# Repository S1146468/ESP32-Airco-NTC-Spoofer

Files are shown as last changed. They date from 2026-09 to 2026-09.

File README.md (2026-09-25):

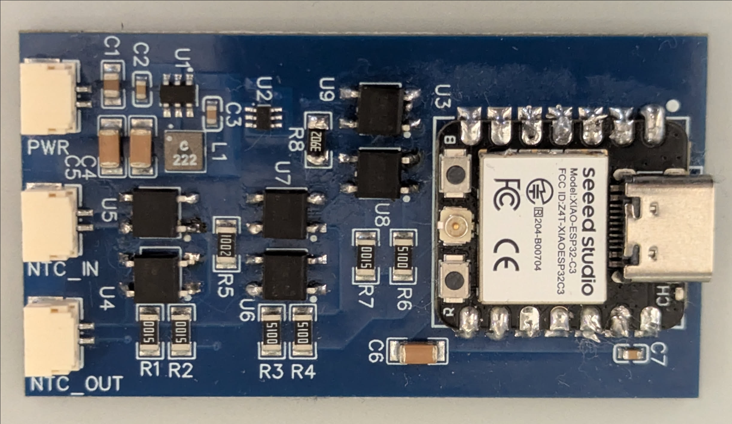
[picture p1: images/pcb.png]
PCB


# ESP32 Airco NTC Spoofer

An ESP32-C3 based open-hardware controller for improving the temperature regulation of a portable air conditioner by taking control of its NTC temperature-sensor input.

Instead of switching mains power or directly controlling the compressor, this project leaves the air conditioner's own electronics in charge and changes only the temperature resistance presented to its NTC input.

## Project goal

The goal of this project is to make a portable air conditioner regulate the temperature of the **room**, rather than relying only on the temperature measured by the air conditioner's built-in NTC sensor.

In my installation, the stock NTC measurement did not represent the room temperature very well. The temperature could continue drifting significantly after the air conditioner had started cooling, resulting in poor regulation and noticeable overshoot.

### Stock NTC

The following trace shows the system operating with the original air-conditioner NTC control.

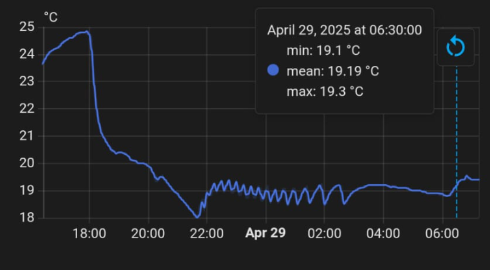
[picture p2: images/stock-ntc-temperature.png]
Temperature with stock NTC


The built-in control reacts to the temperature measured at the air conditioner itself. Depending on the unit, airflow, sensor placement, and room layout, that temperature can differ substantially from the temperature at the location that actually matters.

### With the NTC spoofer

The following trace shows the same air conditioner being controlled through the ESP32 NTC spoofer.

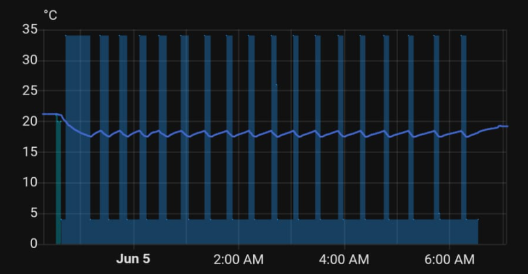
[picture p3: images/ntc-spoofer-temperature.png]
Temperature with ESP32 NTC spoofer


With the spoofer active, a Home Assistant room-temperature sensor becomes the input for an ESPHome thermostat.

The air conditioner is then deliberately shown one of two simulated NTC temperatures:

```text
35 °C -> cooling required
5 °C  -> target satisfied
```

The large transitions in the second graph are therefore intentional. They are the simulated NTC temperatures used to make the air conditioner's own controller start or stop requesting cooling.

The actual room-temperature trace can then be regulated using the external room sensor instead of depending on the location of the air conditioner's internal NTC.

These plots are examples from my installation rather than a controlled laboratory A/B test, but they illustrate the problem this project is intended to solve.

## How it works

The PCB sits between the air conditioner's original NTC sensor and the air-conditioner controller.

It can present one of three states:

```text
                         +----------------------+
Original NTC ------------|                      |
                         |  ESP32 NTC Spoofer   |----> Air-conditioner NTC input
39 kΩ / ~5 °C -----------|                      |
                         |                      |
10 kΩ / ~35 °C ----------|                      |
                         +----------------------+
                                   ^
                                   |
                              XIAO ESP32-C3
```

The ESP32 does **not** directly control the compressor.

The portable air conditioner's original controller still handles:

- compressor operation;
- internal compressor protection;
- fan behaviour;
- fault handling;
- the rest of the normal air-conditioner control logic.

The ESP32 only changes the temperature resistance seen at the NTC input.

## Control principle

The ESPHome firmware receives the room temperature and air-conditioner state from Home Assistant.

When cooling is required:

```text
Room too warm
    |
    v
ESPHome thermostat -> COOL
    |
    v
35 °C spoof selected
    |
    v
Air conditioner sees a warm NTC
    |
    v
Air conditioner continues cooling
```

When the target temperature has been reached:

```text
Target satisfied
    |
    v
ESPHome thermostat -> IDLE
    |
    v
5 °C spoof selected
    |
    v
Air conditioner sees a cold NTC
    |
    v
Air conditioner stops requesting cooling
```

When external control is inactive, the original NTC is reconnected.

## Hardware fail-safe

The PCB is designed so that loss of control power returns the NTC interface to the original sensor path:

```text
Original NTC -> connected
5 °C spoof   -> disconnected
35 °C spoof  -> disconnected
```

The original NTC path uses normally-closed PhotoMOS relays, while the spoof paths use normally-open PhotoMOS relays.

This means the hardware falls back to the air conditioner's own sensor when the controller is not powered.

## GPIO mapping

The corrected PCB and firmware mapping is:

| XIAO ESP32-C3 | GPIO | Function |
|---|---:|---|
| D2 | GPIO4 | Original air-conditioner NTC path |
| D3 | GPIO5 | 5 °C spoof path / 39 kΩ |
| D4 | GPIO6 | 35 °C spoof path / 10 kΩ |

The resistor values and firmware GPIO mapping must agree with the PCB.

## Firmware

Two ESPHome configurations are included.

### Two-room version

[`firmware/esp32-airco-ntc-spoofer-double-room.yaml`](firmware/esp32-airco-ntc-spoofer-double-room.yaml)

Supports two Home Assistant room-temperature sensors and an `Airco Area` selector:

```text
None
Room 1
Room 2
```

This version preserves the behaviour of the original two-room firmware.

### Single-room version

[`firmware/esp32-airco-ntc-spoofer-single-room.yaml`](firmware/esp32-airco-ntc-spoofer-single-room.yaml)

Uses one fixed Home Assistant room-temperature sensor and contains additional software fail-safe checks.

For the complete firmware explanation, configuration instructions, diagrams, thermostat behaviour, and compressor timing procedure, see:

**[Firmware documentation](firmware/firmware.md)**

## Hardware

The repository includes the complete PCB design and manufacturing files:

- EasyEDA schematic source;
- EasyEDA PCB source;
- schematic PDF;
- PCB PDF;
- Gerbers;
- BOM;
- pick-and-place file;
- OBJ mechanical model.

For PCB details, component information, manufacturing settings, and hardware verification, see:

**[Hardware documentation](hardware/hardware.md)**

## Repository structure

```text
ESP32-Airco-NTC-Spoofer/
├── README.md
├── LICENSE.md
├── LICENSES/
│   ├── CERN-OHL-S-2.0.txt
│   └── GPL-3.0-only.txt
│
├── images/
│   ├── stock-ntc-temperature.png
│   └── ntc-spoofer-temperature.png
│
├── firmware/
│   ├── firmware.md
│   ├── esp32-airco-ntc-spoofer-double-room.yaml
│   ├── esp32-airco-ntc-spoofer-single-room.yaml
│   ├── secrets.example.yaml
│   └── docs/
│
└── hardware/
    ├── hardware.md
    ├── assembly/
    ├── bom/
    ├── docs/
    ├── easyeda/
    ├── gerbers/
    └── mechanical/
```

## Getting started

A typical build consists of:

1. Manufacture and assemble the PCB using the files in [`hardware/`](hardware/).
2. Verify the original NTC fallback path before connecting the board to the air conditioner.
3. Connect the original NTC to `NTC_IN`.
4. Connect `NTC_OUT` to the air conditioner's NTC input.
5. Power the controller according to the schematic.
6. Choose the single-room or two-room ESPHome configuration.
7. Configure the Home Assistant entity IDs and ESPHome secrets.
8. Compile and flash the XIAO ESP32-C3.
9. Verify the 5 °C, 35 °C, and original-NTC states.
10. Observe several normal cooling cycles before relying on the system unattended.

See the [firmware documentation](firmware/firmware.md) and [hardware documentation](hardware/hardware.md) for the detailed procedure.

## Compressor cycling

Because this project adds an external thermostat in front of the air conditioner's own control system, the ESPHome thermostat includes minimum ON and OFF times.

The default configuration is:

```yaml
min_off_time: "4min"
min_on_time: "6min"
min_idle_time: "0s"
```

These values should be checked against the behaviour and documentation of the air conditioner being controlled.

The firmware documentation contains a practical procedure for measuring normal compressor cycling with a power-monitoring smart plug:

[Compressor timing and tuning](firmware/firmware.md#tuning-min_off_time-and-min_on_time)

## Important limitations

This project is intended for low-voltage NTC sensor interfacing.

It is **not** a mains-power switching project.

Before using the controller:

- verify the NTC connector pinout;
- verify the board-power connector pinout;
- verify the spoof resistances with a multimeter;
- verify that the original NTC is restored when control is inactive;
- verify normal compressor cycling;
- use manufacturer or service-manual protection limits when available.

The resistance-to-temperature relationship is specific to the NTC curve used by the air conditioner. The 39 kΩ and 10 kΩ values are the values used for this particular design and should not automatically be assumed to match every air conditioner.

## Project status

The project contains a working hardware design, manufacturing outputs, and ESPHome firmware for controlling a portable air conditioner through its NTC input.

The current hardware uses:

```text
XIAO ESP32-C3
CPC1117NTR normally-closed PhotoMOS relays
CPC1017NTR normally-open PhotoMOS relays
39 kΩ cold-spoof resistor
10 kΩ warm-spoof resistor
```

If adapting the project to another air conditioner, first determine the NTC resistance curve and verify that the spoof resistance values are appropriate for that unit.

## License

This repository contains separately licensed firmware and hardware.

| Part | License |
|---|---|
| Firmware / software | GNU GPL v3 only (`GPL-3.0-only`) |
| Hardware design | CERN Open Hardware Licence v2 - Strongly Reciprocal (`CERN-OHL-S-2.0`) |

See [LICENSE.md](LICENSE.md) for the licensing overview and [`LICENSES/`](LICENSES/) for the full license texts.

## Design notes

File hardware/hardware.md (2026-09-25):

# Hardware

This directory contains the editable PCB design, fabrication outputs, assembly data, mechanical export, and reference documentation for the **ESP32 Airco NTC Spoofer**.

The board is designed to sit between a portable air conditioner's original NTC temperature sensor and the air-conditioner controller. An ESP32-C3 can select the original NTC or one of two fixed-resistance spoof paths.

The PCB does **not** directly switch the compressor or mains power. It only changes what the air conditioner's NTC input sees.

For firmware setup and thermostat behaviour, see:

[../firmware/firmware.md](../firmware/firmware.md)

## Contents

### Editable EasyEDA source

- [Schematic source](easyeda/SCH_ESP32-Airco-NTC-Spoofer-Schematic.json)
- [PCB source](easyeda/PCB_ESP32-Airco-NTC-Spoofer-PCB.json)

### Design documents

- [Schematic PDF](docs/Schematic_ESP32-Airco-NTC-Spoofer.pdf)
- [PCB PDF](docs/PCB_ESP32-Airco-NTC-Spoofer-PCB.pdf)

### Manufacturing files

- [Gerber ZIP](gerbers/Gerber_ESP32-Airco-NTC-Spoofer.zip)
- [Individual Gerber and drill files](gerbers/Gerber_Export/)
- [Bill of materials](bom/BOM_ESP32-Airco-NTC-Spoofer.csv)
- [Pick-and-place file](assembly/PickAndPlace_ESP32-Airco-NTC-Spoofer-PCB.csv)

### Mechanical files

- [OBJ 3D model](mechanical/OBJ_ESP32-Airco-NTC-Spoofer-PCB.obj)
- [OBJ material file](mechanical/OBJ_ESP32-Airco-NTC-Spoofer-PCB.mtl)

## Directory structure

```text
hardware/
├── assembly/
│   └── PickAndPlace_ESP32-Airco-NTC-Spoofer-PCB.csv
├── bom/
│   └── BOM_ESP32-Airco-NTC-Spoofer.csv
├── docs/
│   ├── PCB_ESP32-Airco-NTC-Spoofer-PCB.pdf
│   └── Schematic_ESP32-Airco-NTC-Spoofer.pdf
├── easyeda/
│   ├── PCB_ESP32-Airco-NTC-Spoofer-PCB.json
│   └── SCH_ESP32-Airco-NTC-Spoofer-Schematic.json
├── gerbers/
│   ├── Gerber_ESP32-Airco-NTC-Spoofer.zip
│   └── Gerber_Export/
├── mechanical/
│   ├── OBJ_ESP32-Airco-NTC-Spoofer-PCB.mtl
│   └── OBJ_ESP32-Airco-NTC-Spoofer-PCB.obj
└── hardware.md
```

## Hardware overview

The design contains three selectable NTC paths:

1. the original air-conditioner NTC;
2. a fixed resistance representing approximately **5 °C**;
3. a fixed resistance representing approximately **35 °C**.

The ESP32 does not measure the air conditioner's NTC input. It controls solid-state relays that determine which path is presented to the air-conditioner controller.

Conceptually:

```text
 Original NTC
     |
     +-------------------+
                         |
 39 kΩ / 5 °C spoof ----+----> NTC switching ----> Air-conditioner NTC input
                         |
 10 kΩ / 35 °C spoof ---+
                         ^
                         |
                    XIAO ESP32-C3
```

The exact relationship between resistance and simulated temperature depends on the NTC curve used by the air conditioner. The 39 kΩ and 10 kΩ values are the values used in this design.

## NTC switching architecture

### Original NTC path

The original sensor path uses:

```text
U4, U5 -> CPC1117NTR
```

These devices form the original NTC pass-through path.

The hardware is designed so that the original NTC path is the fallback state when the control electronics are not actively spoofing the temperature.

### 5 °C spoof path

The 5 °C spoof path uses:

```text
R5 = 39 kΩ
GPIO5 / XIAO D3
NTC_5C
```

The firmware activates this path when it wants the air conditioner to see a cold temperature.

### 35 °C spoof path

The 35 °C spoof path uses:

```text
R8 = 10 kΩ
GPIO6 / XIAO D4
NTC_35C
```

The firmware activates this path when it wants the air conditioner to see a warm temperature.

### GPIO mapping

The PCB and firmware must use the same mapping:

| XIAO ESP32-C3 | GPIO | PCB net | Function |
|---|---:|---|---|
| D2 | GPIO4 | `NTC_AIRCO` | Original NTC path control |
| D3 | GPIO5 | `NTC_5C` | 5 °C spoof path |
| D4 | GPIO6 | `NTC_35C` | 35 °C spoof path |

For the matching firmware configuration, see:

[../firmware/firmware.md](../firmware/firmware.md)

## Fail-safe behaviour

The hardware uses different relay types for the original sensor path and the spoof paths.

The intended unpowered / fallback state is:

```text
Original NTC -> connected
5 °C spoof   -> disconnected
35 °C spoof  -> disconnected
```

This is important because a loss of ESP32 control should return temperature sensing to the original air-conditioner NTC rather than intentionally forcing either spoof resistance.

The firmware should preserve the same principle whenever external control is inactive.

Before installing the board, verify this behaviour with a multimeter.

## Main components

The current BOM contains the following major devices:

| Reference | Part | Function |
|---|---|---|
| U3 | XIAO ESP32-C3 | Main controller |
| U4, U5 | CPC1117NTR | Original NTC switching path |
| U6-U9 | CPC1017NTR | Spoof-path switching |
| R5 | 39 kΩ | 5 °C spoof resistor |
| R8 | 10 kΩ | 35 °C spoof resistor |
| U1 | AP63205WU-7 | Power conversion |
| U2 | LM66100DCKR | Power-path circuitry |
| NTC_IN | JST SM02B-GHS-TB(LF)(SN) | Original NTC connection |
| NTC_OUT | JST SM02B-GHS-TB(LF)(SN) | Air-conditioner NTC input connection |
| PWR | JST SM02B-GHS-TB(LF)(SN) | Board power connection |

The complete component list, manufacturer part numbers, and LCSC part numbers are available in:

[BOM_ESP32-Airco-NTC-Spoofer.csv](bom/BOM_ESP32-Airco-NTC-Spoofer.csv)

## Connectors

The board contains three main connectors:

```text
PWR
NTC_IN
NTC_OUT
```

### `NTC_IN`

Connect the original air-conditioner NTC sensor to `NTC_IN`.

### `NTC_OUT`

Connect `NTC_OUT` to the air-conditioner controller where the original NTC would normally connect.

The board then selects whether `NTC_OUT` sees:

- the real sensor;
- the 5 °C spoof resistance;
- the 35 °C spoof resistance.

### `PWR`

`PWR` supplies the PCB electronics.

Refer to the schematic before connecting power. Do not assume that the NTC connector and power connector use the same voltage or pinout.

## Editable design files

The board was designed with **EasyEDA Standard**.

The editable source files are:

- [`easyeda/SCH_ESP32-Airco-NTC-Spoofer-Schematic.json`](easyeda/SCH_ESP32-Airco-NTC-Spoofer-Schematic.json)
- [`easyeda/PCB_ESP32-Airco-NTC-Spoofer-PCB.json`](easyeda/PCB_ESP32-Airco-NTC-Spoofer-PCB.json)

No custom schematic symbols or PCB footprints are required by the current design.

### Opening the source in EasyEDA Standard

In EasyEDA Standard:

1. open EasyEDA;
2. select **File -> Open -> EasyEDA...**;
3. select the JSON file;
4. import/save it into a project if you want to edit it.

The schematic and PCB JSON files are the authoritative editable hardware source.

The PDFs, Gerbers, BOM, pick-and-place data, and OBJ model are generated outputs.

## Schematic and PCB PDFs

PDF exports are included so the design can be inspected without EasyEDA.

### Schematic

[Open the schematic PDF](docs/Schematic_ESP32-Airco-NTC-Spoofer.pdf)

### PCB

[Open the PCB PDF](docs/PCB_ESP32-Airco-NTC-Spoofer-PCB.pdf)

If the EasyEDA source is changed, regenerate these PDFs so the documentation remains synchronized with the editable design.

## PCB manufacturing specifications

The first boards were manufactured by JLCPCB using the following configuration:

| Parameter | Specification |
|---|---|
| Base material | FR-4 |
| Layer count | 4 |
| Board dimensions | 31.29 mm × 57.78 mm |
| PCB thickness | 1.6 mm |
| Material Tg | TG135 |
| Solder mask | Blue |
| Silkscreen | White |
| Surface finish | HASL with lead |
| Outer copper weight | 1 oz |
| Inner copper weight | 0.5 oz |
| Via covering | Plugged |
| Minimum via hole | 0.30 mm |
| Electrical test | Flying probe, fully tested |
| Quality standard | IPC Class 2 |
| Board outline tolerance | ±0.2 mm |
| Specified stackup | No |
| Gold fingers | No |
| Castellated holes | No |
| Press-fit holes | No |
| Edge plating | No |
| Blind slots | No |
| Backdrilling | No |
| Countersink holes | No |
| Deburring / edge rounding | No |
| UL marking | No |
| Silkscreen technology | Ink-jet printing |

The original JLCPCB order reported the minimum via setting as approximately:

```text
0.3 mm hole / 0.4-0.45 mm diameter
```

Treat the EasyEDA PCB design and the fabrication house's current design-rule check as authoritative when placing a new order.

## Layer structure

The board uses four copper layers:

```text
Layer 1 -> Top copper
Layer 2 -> Inner layer 1
Layer 3 -> Inner layer 2
Layer 4 -> Bottom copper
```

No specific manufacturer dielectric stackup was requested for the original build.

If the design is changed in a way that depends on controlled impedance, dielectric thickness, or a specific return-plane geometry, define a stackup explicitly rather than relying on the manufacturer's standard four-layer construction.

## Gerber files

The fabrication ZIP is:

[Gerber_ESP32-Airco-NTC-Spoofer.zip](gerbers/Gerber_ESP32-Airco-NTC-Spoofer.zip)

The individual exported files are available in:

[gerbers/Gerber_Export/](gerbers/Gerber_Export/)

The current Gerber export contains:

```text
Drill_PTH_Through.DRL
Drill_PTH_Through_Via.DRL
Gerber_BoardOutlineLayer.GKO
Gerber_BottomLayer.GBL
Gerber_BottomSolderMaskLayer.GBS
Gerber_DocumentLayer.GDL
Gerber_InnerLayer1.G1
Gerber_InnerLayer2.G2
Gerber_TopLayer.GTL
Gerber_TopPasteMaskLayer.GTP
Gerber_TopSilkscreenLayer.GTO
Gerber_TopSolderMaskLayer.GTS
```

There is no bottom paste or bottom silkscreen file in the current export.

Before sending the ZIP to a board manufacturer, inspect it in a Gerber viewer.

Check at minimum:

- board outline;
- all four copper layers;
- plated-through-hole drills;
- via drills;
- solder-mask openings;
- top silkscreen;
- top paste layer;
- connector orientation.

## BOM

The bill of materials is:

[BOM_ESP32-Airco-NTC-Spoofer.csv](bom/BOM_ESP32-Airco-NTC-Spoofer.csv)

The BOM includes manufacturer and LCSC part numbers for the current design.

Before ordering:

- verify that the required parts are still available;
- verify that substitutions have compatible electrical characteristics;
- verify package and footprint compatibility;
- pay particular attention to the relay type and default contact state;
- verify that R5 remains 39 kΩ and R8 remains 10 kΩ.

Do not silently substitute the normally-closed original-NTC relay with a normally-open equivalent.

## Pick-and-place file

The assembly position file is:

[PickAndPlace_ESP32-Airco-NTC-Spoofer-PCB.csv](assembly/PickAndPlace_ESP32-Airco-NTC-Spoofer-PCB.csv)

When ordering PCBA assembly, always inspect the manufacturer's placement preview.

Verify:

- connector orientation;
- XIAO ESP32-C3 orientation;
- relay orientation;
- resistor values;
- polarity-sensitive parts;
- rotation of small IC packages.

Do not assume that a successful BOM/CPL import means all rotations are correct.

## Mechanical model

EasyEDA Standard exports the PCB assembly as OBJ rather than native STEP.

The current mechanical files are:

- [`OBJ_ESP32-Airco-NTC-Spoofer-PCB.obj`](mechanical/OBJ_ESP32-Airco-NTC-Spoofer-PCB.obj)
- [`OBJ_ESP32-Airco-NTC-Spoofer-PCB.mtl`](mechanical/OBJ_ESP32-Airco-NTC-Spoofer-PCB.mtl)

These files are suitable for visualization and approximate enclosure/layout work.

A native STEP file is not included.

If precise mechanical CAD integration is required, prefer a native STEP export from a CAD tool capable of producing proper solid geometry rather than simply converting the OBJ mesh and assuming it is equivalent.

## Regenerating manufacturing files

When the schematic or PCB is modified, use the editable EasyEDA source as the starting point.

A typical release workflow is:

1. modify the EasyEDA schematic;
2. update/synchronize the PCB if required;
3. run ERC on the schematic;
4. run DRC on the PCB;
5. regenerate the schematic PDF;
6. regenerate the PCB PDF;
7. regenerate the Gerber ZIP;
8. regenerate the BOM;
9. regenerate the pick-and-place file;
10. regenerate the OBJ model if the physical layout changed;
11. inspect the Gerbers;
12. compare the new outputs with the previous revision before publishing.

Generated manufacturing outputs should not be edited manually to create a design change.

## Hardware verification

Before ordering or installing a new revision, check the following.

### Design checks

- [ ] EasyEDA ERC completed.
- [ ] EasyEDA PCB DRC completed.
- [ ] Schematic and PCB source correspond to the same revision.
- [ ] Schematic PDF regenerated.
- [ ] PCB PDF regenerated.
- [ ] Gerbers regenerated from the current PCB.
- [ ] BOM regenerated from the current schematic/PCB.
- [ ] Pick-and-place file regenerated.
- [ ] Gerbers inspected in an independent viewer.

### NTC path checks

- [ ] GPIO4 controls the original NTC path.
- [ ] GPIO5 controls `NTC_5C`.
- [ ] GPIO6 controls `NTC_35C`.
- [ ] R5 is 39 kΩ.
- [ ] R8 is 10 kΩ.
- [ ] Original NTC passes through when the hardware is in its fallback state.
- [ ] 5 °C spoof path is isolated when inactive.
- [ ] 35 °C spoof path is isolated when inactive.
- [ ] Only the intended spoof resistance is connected when each spoof path is enabled.

### Assembly checks

- [ ] `NTC_IN` and `NTC_OUT` are not reversed during installation.
- [ ] `PWR` polarity/pinout is verified from the schematic.
- [ ] XIAO ESP32-C3 orientation is correct.
- [ ] Relay part numbers match the BOM.
- [ ] R5 and R8 values are physically verified.
- [ ] No solder bridges are present around the NTC switching circuitry.

## Bench testing before installation

Before connecting the PCB to an air conditioner, perform basic continuity and resistance checks.

With the board in its fallback state, verify that the original NTC path connects through from `NTC_IN` to `NTC_OUT`.

Then test the spoof states and confirm that the resistance visible at `NTC_OUT` changes to the expected value.

Do not connect the PCB to unknown high-voltage wiring. The design is intended for the air conditioner's low-voltage NTC sensing circuit and its intended board-power connection.

## Source vs generated files

The repository separates editable source from generated outputs.

### Editable source

```text
easyeda/*.json
```

### Generated documentation

```text
docs/*.pdf
```

### Generated fabrication data

```text
gerbers/*
bom/*
assembly/*
```

### Generated mechanical data

```text
mechanical/*.obj
mechanical/*.mtl
```

When there is a disagreement between generated files and the editable design source, stop and determine which revision is correct before manufacturing.

## Versioning

For released hardware revisions, record both a hardware revision and a repository release version.

For example:

```text
Hardware revision: REV 1.0
Repository release: v1.0.0
```

When the physical PCB changes, update the hardware revision and regenerate the manufacturing outputs.

Changes that affect only documentation do not necessarily require a new PCB revision.

## License

The hardware design files in this directory are licensed under the
**CERN Open Hardware Licence Version 2 - Strongly Reciprocal
(CERN-OHL-S-2.0)**.

See [CERN-OHL-S-2.0.txt](../LICENSES/CERN-OHL-S-2.0.txt).

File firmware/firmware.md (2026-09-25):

# Firmware

This directory contains the ESPHome firmware for the **ESP32 Airco NTC Spoofer**.

The firmware uses one or more Home Assistant room-temperature sensors together with a Home Assistant climate entity. The ESP32 runs a local thermostat and controls which resistance the portable air conditioner sees on its original NTC temperature-sensor input.

The PCB does **not** directly switch the compressor or the mains supply. The portable air conditioner's own electronics remain responsible for operating and protecting the compressor.

## Contents

- [Two-room firmware](esp32-airco-ntc-spoofer-double-room.yaml)
- [Single-room firmware](esp32-airco-ntc-spoofer-single-room.yaml)
- [Example secrets file](secrets.example.yaml)
- [Editable Draw.io diagrams](docs/firmware-diagrams.drawio)

## Firmware variants

### Two-room configuration

Use:

[`esp32-airco-ntc-spoofer-double-room.yaml`](esp32-airco-ntc-spoofer-double-room.yaml)

This version supports two Home Assistant room-temperature sensors and provides an `Airco Area` selector.

The available selections are:

```text
None
Room 1
Room 2
```

The selected room sensor becomes the temperature input for the local ESPHome thermostat.

This configuration intentionally preserves the control behaviour of the original two-room firmware. Installation-specific names and Home Assistant entity IDs have been moved into `substitutions`, and the corrected GPIO mapping is used.

### Single-room configuration

Use:

[`esp32-airco-ntc-spoofer-single-room.yaml`](esp32-airco-ntc-spoofer-single-room.yaml)

This version is intended for installations with one fixed room-temperature sensor.

It removes:

- the second room sensor;
- the `Airco Area` selector;
- the room-selection logic.

The single-room configuration also contains additional fail-safe checks, including Home Assistant API connectivity and explicit restoration of the original NTC path if the control state becomes invalid.

## Hardware / GPIO mapping

The firmware expects the corrected PCB mapping:

| XIAO ESP32-C3 | GPIO | Function |
|---|---:|---|
| D2 | GPIO4 | Original air-conditioner NTC path |
| D3 | GPIO5 | 5 °C spoof path |
| D4 | GPIO6 | 35 °C spoof path |

The resistor placement and firmware GPIO assignment must agree with this table.

The intended spoof mapping is:

```text
GPIO5 -> NTC_5C  -> cold simulated temperature
GPIO6 -> NTC_35C -> warm simulated temperature
```

## UML diagrams

The firmware diagrams are stored in [`docs/`](docs/).

The editable diagrams.net / Draw.io source is:

[`docs/firmware-diagrams.drawio`](docs/firmware-diagrams.drawio)

### System architecture

The architecture diagram shows how Home Assistant, the ESPHome thermostat, the GPIO outputs, the NTC switching hardware, and the portable air conditioner interact.

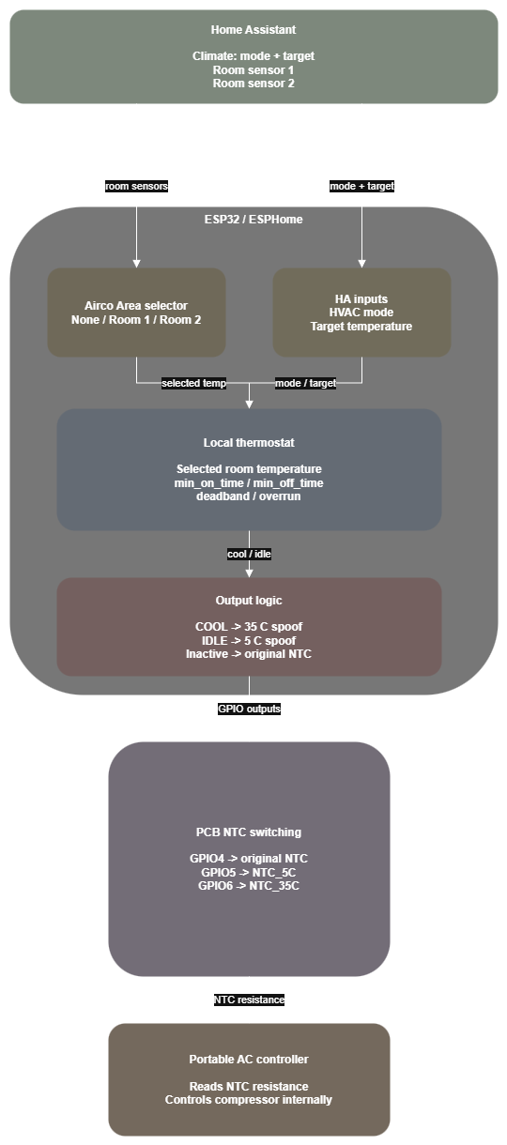
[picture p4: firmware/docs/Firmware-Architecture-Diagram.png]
Firmware architecture


The important boundary is that the ESP32 does not directly command the compressor. It changes the resistance presented to the air conditioner's NTC input. The air conditioner's own controller still decides when to run the compressor.

### Control-state diagram

The control-state diagram shows the main decisions made by the two-room firmware before NTC spoofing is enabled.

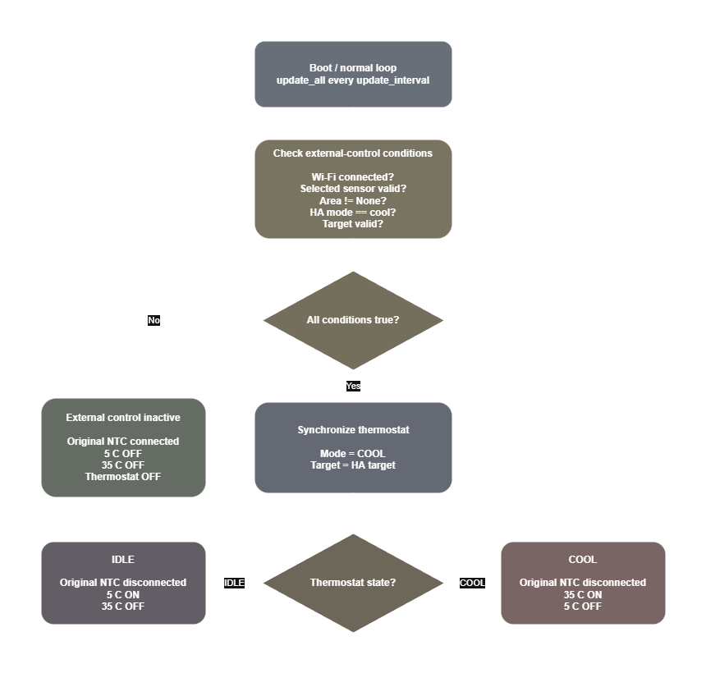
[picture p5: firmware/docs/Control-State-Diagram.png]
Control state diagram


If external control is inactive, the original NTC path is used.

The thermostat states correspond to:

```text
COOL
  -> current_state_ntc_35c = true
  -> current_state_ntc_5c  = false

IDLE
  -> current_state_ntc_5c  = true
  -> current_state_ntc_35c = false
```

### Update sequence

The sequence diagram shows the execution order used by the two-room `update_all` script.

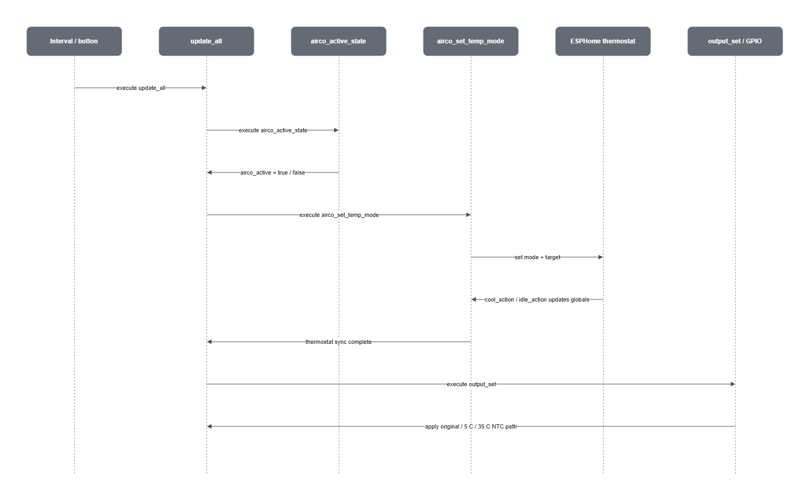
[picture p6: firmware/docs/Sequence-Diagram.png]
Firmware update sequence


The order is intentionally:

```text
update_all
    |
    +--> airco_active_state
    |
    +--> airco_set_temp_mode
    |
    +--> output_set
```

This matters because `airco_set_temp_mode` can cause the thermostat to update `current_state_ntc_5c` or `current_state_ntc_35c` before `output_set` applies the corresponding GPIO states.

## Operating principle

The original portable air conditioner uses an NTC temperature sensor.

This PCB sits between that sensor and the air-conditioner controller and can present one of three temperature-sensing states:

```text
Original NTC
5 °C spoof
35 °C spoof
```

Conceptually:

```text
                           +-------------------+
Original NTC -------------|                   |
                           | NTC switching PCB |----> Air-conditioner NTC input
5 °C resistor ------------|                   |
                           |                   |
35 °C resistor -----------|                   |
                           +-------------------+
                                    ^
                                    |
                                 ESP32-C3
```

When external control is inactive, the original NTC is used.

When external thermostat control is active, the ESP32 selects either the 5 °C or the 35 °C spoof resistance.

## Thermostat behaviour

Home Assistant supplies:

- the current room temperature;
- the requested HVAC mode;
- the requested target temperature.

The ESP32 runs an ESPHome thermostat using the selected room-temperature sensor.

When the local thermostat requires cooling:

```text
35 °C spoof selected
```

The portable air conditioner sees a warm simulated temperature and therefore continues cooling.

When the target temperature has been satisfied:

```text
5 °C spoof selected
```

The portable air conditioner sees a cold simulated temperature and therefore stops requesting cooling.

The portable air conditioner's own controller remains responsible for actual compressor operation.

## Two-room control flow

The two-room configuration works as follows:

```text
Room 1 sensor -----+
                   |
                   +----> Airco Area selector ----> room_temp
                   |
Room 2 sensor -----+

Home Assistant climate mode --------+
                                     |
Home Assistant target temperature ---+----> ESPHome thermostat
                                     |
room_temp ---------------------------+
```

Configure the installation-specific values under `substitutions`:

```yaml
substitutions:
  device_name: "esp32-airco-ntc-spoofer"
  friendly_name: "ESP32 Airco NTC Spoofer"

  room_1_name: "Living Room"
  room_2_name: "Bedroom"

  room_1_temperature_entity: "sensor.living_room_temperature"
  room_2_temperature_entity: "sensor.bedroom_temperature"

  airco_climate_entity: "climate.portable_air_conditioner"

  update_interval: "5s"

  min_off_time: "4min"
  min_on_time: "6min"
  min_idle_time: "0s"
```

When `None` is selected for `Airco Area`, external NTC spoofing is disabled and the original NTC is used.

### When two-room external control is active

The two-room firmware considers external control active only when all of the following are true:

- Wi-Fi is connected;
- the selected room-temperature sensor contains a valid value;
- `Airco Area` is not `None`;
- the Home Assistant climate entity reports `cool`;
- the Home Assistant target temperature contains a valid numeric value.

These conditions are evaluated by:

```text
airco_active_state
```

The main control loop runs every:

```yaml
update_interval: "5s"
```

by default.

## Single-room control flow

The single-room configuration uses one fixed room sensor:

```text
Room temperature -------------------+
                                    |
Home Assistant climate mode --------+----> ESPHome thermostat
                                    |
Home Assistant target temperature --+
```

Configure it with:

```yaml
substitutions:
  device_name: "esp32-airco-ntc-spoofer"
  friendly_name: "ESP32 Airco NTC Spoofer"

  room_temperature_entity: "sensor.living_room_temperature"
  airco_climate_entity: "climate.portable_air_conditioner"

  update_interval: "5s"

  min_off_time: "4min"
  min_on_time: "6min"
  min_idle_time: "0s"

  cool_deadband: "0.1 °C"
  cool_overrun: "0.35 °C"
```

The single-room version additionally requires an active Home Assistant ESPHome API connection before external spoof control is enabled.

If the required state becomes invalid, the single-room firmware restores:

```text
Original NTC -> connected
5 °C spoof   -> disconnected
35 °C spoof  -> disconnected
```

## NTC output states

### External control inactive

```text
Original NTC -> connected
5 °C spoof   -> disconnected
35 °C spoof  -> disconnected
```

### Cooling requested

```text
Original NTC -> disconnected
5 °C spoof   -> disconnected
35 °C spoof  -> connected
```

### Target satisfied

```text
Original NTC -> disconnected
5 °C spoof   -> connected
35 °C spoof  -> disconnected
```

## Thermostat hysteresis

The firmware uses thermostat hysteresis to prevent excessive switching around the target temperature.

The default settings are:

```yaml
cool_deadband: 0.1 °C
cool_overrun: 0.35 °C
```

For a target of:

```text
22.0 °C
```

cooling begins at approximately:

```text
22.0 + 0.1 = 22.1 °C
```

and stops at approximately:

```text
22.0 - 0.35 = 21.65 °C
```

A wider hysteresis generally gives longer cooling cycles and fewer compressor starts.

A narrower hysteresis gives tighter room-temperature regulation but can increase cycling frequency.

## Compressor protection settings

The important thermostat timing settings are:

```yaml
substitutions:
  min_off_time: "4min"
  min_on_time: "6min"
  min_idle_time: "0s"
```

These are passed to the ESPHome thermostat as:

```yaml
min_cooling_off_time: ${min_off_time}
min_cooling_run_time: ${min_on_time}
min_idle_time: ${min_idle_time}
```

### `min_off_time`

`min_off_time` is the minimum amount of time cooling must remain OFF before the thermostat may request cooling again.

Example:

```yaml
min_off_time: "4min"
```

After cooling stops, the external thermostat will not request another cooling cycle for at least four minutes.

This helps prevent rapid compressor restarts.

### `min_on_time`

`min_on_time` is the minimum amount of time cooling must remain active before the thermostat may transition back to idle.

Example:

```yaml
min_on_time: "6min"
```

Once the thermostat requests cooling, it will keep the cooling state active for at least six minutes.

### `min_idle_time`

The default is:

```yaml
min_idle_time: "0s"
```

For this project, compressor restart protection is primarily handled by `min_off_time`.

`min_idle_time` normally does not need to duplicate the same delay unless the installation requires it.

# Tuning `min_off_time` and `min_on_time`

The timing values should be tuned for the portable air conditioner being controlled.

A practical way to estimate suitable values is to connect the portable air conditioner to a **power-monitoring smart-home plug** and observe the compressor's normal ON and OFF cycling.

> [!IMPORTANT]
> The air conditioner must be **actively regulating room temperature** during this measurement.
>
> If the room is much warmer than the setpoint and the compressor simply runs continuously, the measurement does not provide useful minimum ON/OFF cycle information.

> [!CAUTION]
> Manufacturer or service-manual compressor timing requirements take precedence over measurements. Do not configure a shorter protection interval than a documented manufacturer requirement.

## Required equipment

You need:

- the portable air conditioner;
- a power-monitoring smart plug;
- access to the plug's live or historical power graph;
- conditions that allow the air conditioner to repeatedly cycle the compressor ON and OFF.

The smart plug must be rated for the air conditioner's voltage, current, and startup load.

## Why power monitoring works

A portable air conditioner normally has clearly different power consumption when the compressor is running compared with fan-only operation.

Conceptually:

```text
High power  -> compressor running
Lower power -> compressor stopped / fan may still be running
```

The fan may continue running while the compressor is stopped, so compressor OFF does **not** necessarily mean that power consumption falls to zero.

A typical trace may look like:

```text
Power
  ^
  |
  |        +---------------+              +---------------+
  |        |  Compressor   |              |  Compressor   |
  |        |      ON       |              |      ON       |
  |--------+               +--------------+               +------
  |
  |          <--- ON --->     <--- OFF --->   <--- ON --->
  |
  +------------------------------------------------------------> time
```

## Measurement procedure

### 1. Connect the smart plug

Connect the portable air conditioner through the power-monitoring smart plug.

Verify that the smart plug updates frequently enough to distinguish compressor starts and stops.

### 2. Let the air conditioner regulate normally

Set the air conditioner to cooling mode.

Choose a target temperature that allows the room to repeatedly cross the air conditioner's own regulation thresholds.

The desired behaviour is:

```text
compressor ON
      |
      v
room cools
      |
      v
compressor OFF
      |
      v
room warms
      |
      v
compressor ON again
```

If the compressor runs continuously, wait until the room is close enough to the setpoint for the air conditioner to begin regulating.

### 3. Record multiple cycles

Do not base the timing on one cycle.

Record several complete compressor cycles:

| Cycle | Compressor ON time | Compressor OFF time |
|---|---:|---:|
| 1 |  |  |
| 2 |  |  |
| 3 |  |  |
| 4 |  |  |
| 5 |  |  |

Try to keep the room conditions reasonably stable during the measurement.

### 4. Determine the observed OFF time

For each cycle:

```text
OFF time =
next compressor start
-
previous compressor stop
```

Example observations:

```text
4m 20s
3m 55s
4m 05s
3m 47s
4m 11s
```

Shortest observed OFF time:

```text
3m 47s
```

A conservative configuration could be:

```yaml
min_off_time: "4min"
```

### 5. Determine the observed ON time

For each cycle:

```text
ON time =
compressor stop
-
compressor start
```

Example observations:

```text
6m 30s
5m 58s
5m 42s
6m 15s
5m 55s
```

Shortest observed ON time:

```text
5m 42s
```

A conservative configuration could be:

```yaml
min_on_time: "6min"
```

### 6. Update the firmware

Change the values in the YAML:

```yaml
substitutions:
  min_off_time: "4min"
  min_on_time: "6min"
```

Then validate, compile, and flash the ESPHome configuration.

## Important limitation of this measurement method

The smart-plug method measures the air conditioner's **observed normal behaviour**.

It does not necessarily reveal the compressor's absolute internal protection limits.

For example, an observed six-minute compressor ON period may simply mean that the room required six minutes to cross the thermostat threshold. It does not prove that the air conditioner contains a six-minute minimum-run timer.

Likewise, an observed OFF period may contain:

```text
internal compressor protection delay
+
time required for the room temperature to rise
```

For this reason:

- prefer manufacturer or service-manual values when available;
- observe multiple cycles;
- do not deliberately force rapid compressor cycling;
- use conservative values;
- round timings upward rather than downward.

The purpose of the measurement is **not** to find the shortest cycle the compressor can survive.

The purpose is to ensure that the external thermostat does not request cycling faster than the portable air conditioner normally does.

## Recommended tuning workflow

1. Connect the portable air conditioner through a suitable power-monitoring smart plug.
2. Let the air conditioner regulate room temperature using its normal controller.
3. Record several compressor ON periods.
4. Record several compressor OFF periods.
5. Find the shortest repeatable ON and OFF periods.
6. Compare those measurements with the configured ESPHome values.
7. Round conservatively upward.
8. Update `min_on_time` and `min_off_time`.
9. Run the air conditioner with the NTC spoofer controlling it.
10. Compare the new compressor cycle behaviour with the original power trace.

If the NTC spoofer causes substantially more frequent compressor starts than the original air-conditioner thermostat, increase the protection timings and/or thermostat hysteresis.

## Example tuning result

Suppose the original air conditioner produces:

| Cycle | ON time | OFF time |
|---|---:|---:|
| 1 | 7:10 | 4:35 |
| 2 | 6:25 | 4:08 |
| 3 | 5:42 | 3:47 |
| 4 | 6:05 | 4:12 |
| 5 | 5:51 | 3:55 |

The shortest observed values are:

```text
ON  = 5m 42s
OFF = 3m 47s
```

A conservative configuration could therefore be:

```yaml
substitutions:
  min_off_time: "4min"
  min_on_time: "6min"
```

## Secrets

Do not commit real Wi-Fi credentials, API encryption keys, OTA passwords, or local network configuration to the public repository.

Use ESPHome's `secrets.yaml`.

An example template is included:

[`secrets.example.yaml`](secrets.example.yaml)

Example:

```yaml
wifi_ssid: "YOUR_WIFI_SSID"
wifi_password: "YOUR_WIFI_PASSWORD"

api_encryption_key: "YOUR_API_ENCRYPTION_KEY"
ota_password: "YOUR_OTA_PASSWORD"

# Optional, when manual_ip is enabled:
device_static_ip: "192.168.1.50"
gateway_ip: "192.168.1.1"
subnet: "255.255.255.0"
```

Both firmware configurations use DHCP by default. Static IP configuration can be enabled if required.

## Commissioning checklist

Before relying on the controller unattended:

- [ ] Verify the correct resistor is fitted to the 5 °C path.
- [ ] Verify the correct resistor is fitted to the 35 °C path.
- [ ] Verify GPIO5 controls `NTC_5C`.
- [ ] Verify GPIO6 controls `NTC_35C`.
- [ ] Verify the original NTC operates correctly when spoof control is inactive.
- [ ] Verify the 5 °C spoof produces the expected air-conditioner response.
- [ ] Verify the 35 °C spoof produces the expected air-conditioner response.
- [ ] Verify the configured Home Assistant room-temperature sensor is correct.
- [ ] For the two-room configuration, verify both `Airco Area` selections.
- [ ] Verify the Home Assistant target temperature is imported correctly.
- [ ] Verify the Home Assistant HVAC mode is imported correctly.
- [ ] Measure several normal compressor ON/OFF cycles.
- [ ] Tune `min_off_time` and `min_on_time`.
- [ ] Observe several complete cycles with the NTC spoofer active.
- [ ] Verify the expected fallback behaviour before unattended use.

## ESPHome reference

ESPHome thermostat documentation:

<https://esphome.io/components/climate/thermostat/>

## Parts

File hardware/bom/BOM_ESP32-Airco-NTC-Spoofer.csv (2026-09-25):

ID | Name | Designator | Footprint | Quantity | Manufacturer Part | Manufacturer | Supplier | Supplier Part | Price | Pins | Contributor | JLCPCB Part Class | link
1 | 10uF | C1 | C0805 | 1 | 0805B106K250NT | FH(风华) | LCSC | C92009 | 0.262 | 2 |  | Extended Part
2 | 100nF | C2 | C0603 | 1 | CC0603KRX7R9BB104 | YAGEO(国巨) | LCSC | C14663 | 0.012 | 2 |  | Basic Part
2 | 100nF | C3 | C0603 | 1 | CC0603KRX7R9BB104 | YAGEO(国巨) | LCSC | C14663 | 0.012 | 2 |  | Basic Part
2 | 100nF | C7 | C0603 | 1 | CC0603KRX7R9BB104 | YAGEO(国巨) | LCSC | C14663 | 0.012 | 2 |  | Basic Part
3 | 22uF | C4 | C1206 | 1 | GCM31CR71A226KE02L | muRata(村田) | LCSC | C126598 | 0.389 | 2 | LCSC | Extended Part
3 | 22uF | C5 | C1206 | 1 | GCM31CR71A226KE02L | muRata(村田) | LCSC | C126598 | 0.389 | 2 | LCSC | Extended Part
3 | 22uF | C6 | C1206 | 1 | GCM31CR71A226KE02L | muRata(村田) | LCSC | C126598 | 0.389 | 2 | LCSC | Extended Part
4 | 2.2uH | L1 | IND-SMD_L3.0-W3.0_XFL3012 | 1 | XFL3012-222MEC | Coilcraft(线艺) | LCSC | C3911432 | 5.479 | 2 | lcsc | Extended Part
5 | SM02B-GHS-TB(LF)(SN) | NTC_IN | CONN-SMD_SM02B-GHS-TB-LF-SN | 1 | SM02B-GHS-TB(LF)(SN) | JST | LCSC | C189893 | 0.544 | 4 | LCSC | Extended Part
5 | SM02B-GHS-TB(LF)(SN) | NTC_OUT | CONN-SMD_SM02B-GHS-TB-LF-SN | 1 | SM02B-GHS-TB(LF)(SN) | JST | LCSC | C189893 | 0.544 | 4 | LCSC | Extended Part
5 | SM02B-GHS-TB(LF)(SN) | PWR | CONN-SMD_SM02B-GHS-TB-LF-SN | 1 | SM02B-GHS-TB(LF)(SN) | JST | LCSC | C189893 | 0.544 | 4 | LCSC | Extended Part
6 | 510Ω | R1 | R1206 | 1 | FRC1206F5100TS | FOJAN(富捷) | LCSC | C2933720 | 0.006 | 2 | lcsc | Extended Part
6 | 510Ω | R2 | R1206 | 1 | FRC1206F5100TS | FOJAN(富捷) | LCSC | C2933720 | 0.006 | 2 | lcsc | Extended Part
6 | 510Ω | R3 | R1206 | 1 | FRC1206F5100TS | FOJAN(富捷) | LCSC | C2933720 | 0.006 | 2 | lcsc | Extended Part
6 | 510Ω | R4 | R1206 | 1 | FRC1206F5100TS | FOJAN(富捷) | LCSC | C2933720 | 0.006 | 2 | lcsc | Extended Part
6 | 510Ω | R6 | R1206 | 1 | FRC1206F5100TS | FOJAN(富捷) | LCSC | C2933720 | 0.006 | 2 | lcsc | Extended Part
6 | 510Ω | R7 | R1206 | 1 | FRC1206F5100TS | FOJAN(富捷) | LCSC | C2933720 | 0.006 | 2 | lcsc | Extended Part
7 | 39kΩ | R5 | R1206 | 1 | FRC1206F3902TS | FOJAN(富捷) | LCSC | C2933691 | 0.006 | 2 | lcsc | Extended Part
8 | 10kΩ | R8 | R1206 | 1 | FRC1206F1002TS | FOJAN(富捷) | LCSC | C2907370 | 0.006 | 2 | lcsc | Extended Part
9 | AP63205WU-7 | U1 | TSOT-23-6_L2.9-W1.6-P0.95-LS2.8-BL | 1 | AP63205WU-7 | DIODES(美台) | LCSC | C2071056 | 0.419 | 6 | LCSC | Extended Part
10 | LM66100DCKR | U2 | SC-70-6_L2.0-W1.3-P0.65-LS2.1-BL | 1 | LM66100DCKR | TI(德州仪器) | LCSC | C2869734 | 0.237 | 6 | LCSC | Extended Part
11 | XIAO-ESP32-C3 | U3 | COMM-SMD_XIAO-ESP32-C3_1 | 1 | XIAO-ESP32-C3 | null | LCSC | C9900252152 |  | 23 | lcsc
12 | CPC1117NTR | U4 | SOP-4_L4.1-W3.8-P2.54-LS6.1-BL | 1 | CPC1117NTR | Littelfuse/IXYS | LCSC | C150424 | 3.437 | 4 | LCSC | Extended Part
12 | CPC1117NTR | U5 | SOP-4_L4.1-W3.8-P2.54-LS6.1-BL | 1 | CPC1117NTR | Littelfuse/IXYS | LCSC | C150424 | 3.437 | 4 | LCSC | Extended Part
13 | CPC1017NTR | U6 | SOP-4_L4.1-W3.8-P2.54-LS6.1-BL | 1 | CPC1017NTR | Littelfuse/IXYS | LCSC | C81521 | 1.99 | 4 | LCSC | Extended Part | https://lcsc.com/eda_search?q=C81521&%26type=1&ref=editor
13 | CPC1017NTR | U7 | SOP-4_L4.1-W3.8-P2.54-LS6.1-BL | 1 | CPC1017NTR | Littelfuse/IXYS | LCSC | C81521 | 1.99 | 4 | LCSC | Extended Part | https://lcsc.com/eda_search?q=C81521&%26type=1&ref=editor
13 | CPC1017NTR | U8 | SOP-4_L4.1-W3.8-P2.54-LS6.1-BL | 1 | CPC1017NTR | Littelfuse/IXYS | LCSC | C81521 | 1.99 | 4 | LCSC | Extended Part | https://lcsc.com/eda_search?q=C81521&%26type=1&ref=editor
13 | CPC1017NTR | U9 | SOP-4_L4.1-W3.8-P2.54-LS6.1-BL | 1 | CPC1017NTR | Littelfuse/IXYS | LCSC | C81521 | 1.99 | 4 | LCSC | Extended Part | https://lcsc.com/eda_search?q=C81521&%26type=1&ref=editor

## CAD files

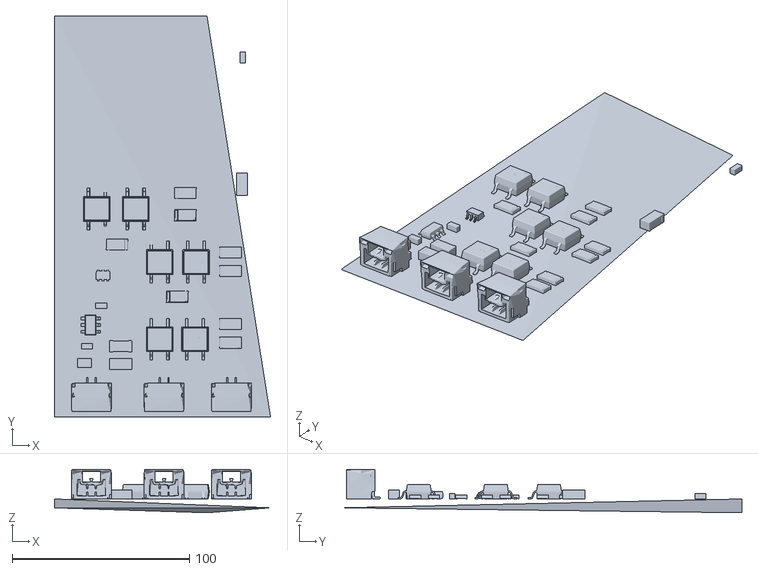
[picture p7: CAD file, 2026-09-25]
hardware/mechanical/OBJ_ESP32-Airco-NTC-Spoofer-PCB.obj
122.0 x 226.3 x 24.5

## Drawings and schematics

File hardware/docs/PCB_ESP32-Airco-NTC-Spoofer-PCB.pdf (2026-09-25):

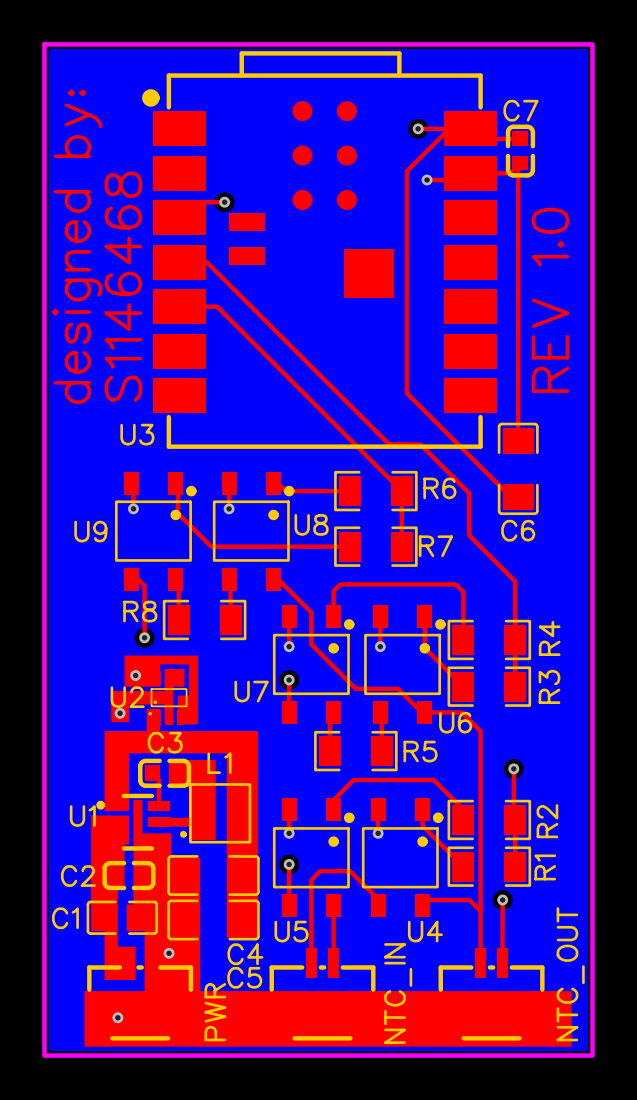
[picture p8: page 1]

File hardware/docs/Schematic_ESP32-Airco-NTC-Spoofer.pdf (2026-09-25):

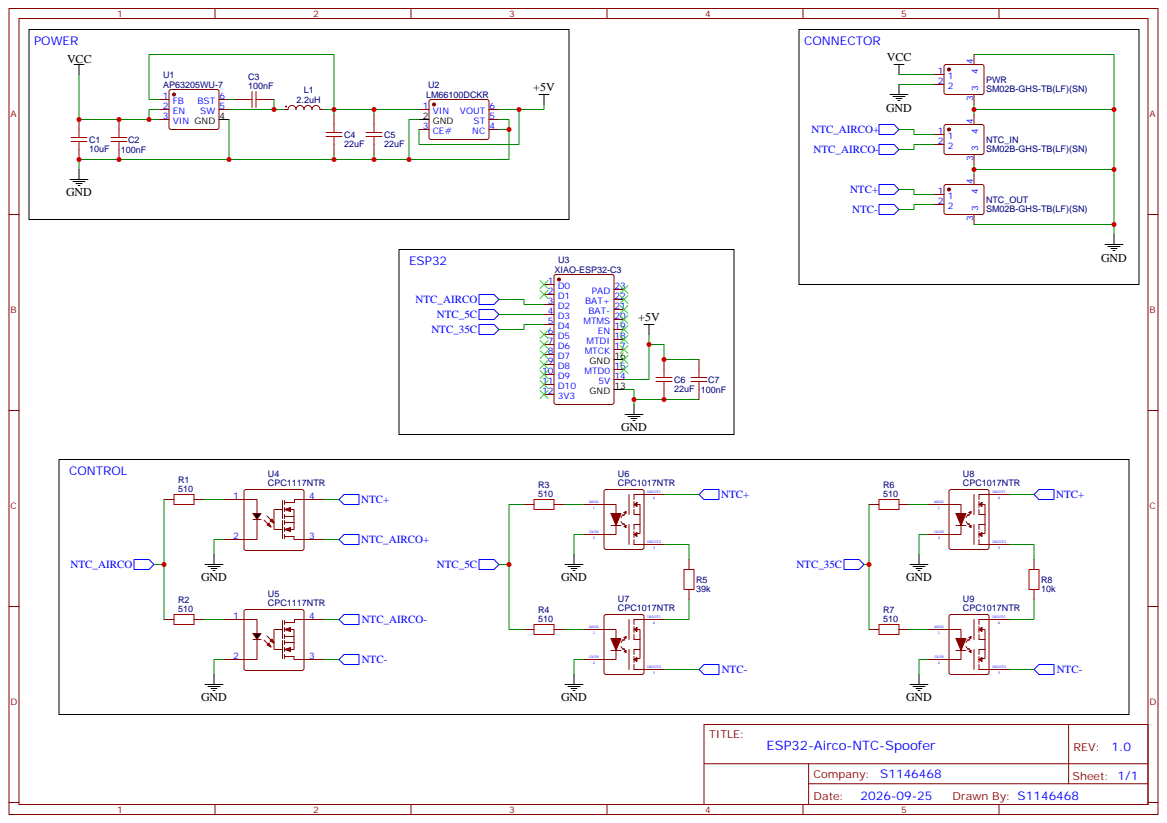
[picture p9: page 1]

SM02B-GHS-TB(LF)(SN)

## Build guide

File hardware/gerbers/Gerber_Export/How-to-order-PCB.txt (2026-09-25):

How to Order PCB

Please refer to:
https://docs.easyeda.com/en/PCB/Order-PCB
